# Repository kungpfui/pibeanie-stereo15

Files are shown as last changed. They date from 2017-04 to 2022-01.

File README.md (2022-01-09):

Pibeanie Stereo15
=================
a [Raspberry Pi] stereo amplifier [HAT] with 2 x 7.5 Watt HiFi output power.

The Problem
-----------
There are stereo amplifier hats on the market like the [Hifiberry Amp+] which work fine and are affordable. I own a Hifiberry Amp+ but this hat has some limitations which result in this little PCB project.

### Existing Limitations ###
- no possibility to mount the [Raspberry Pi 7" display] in an easy way together with the amplifier hat because the PCB has no cutout for the display flex-cable
- no pin header to supply the [Raspberry Pi 7" display] from the hat directly
- on-board 5 Volt DC/DC converter is limited to ~1.0 Ampere
- no infrared receiver

and last and least: as a professional PCB designer I was a little bit shocked by the PCB design of the [Hifiberry Amp+]. There are very small traces where high currents flow and the component placement of the audio output stage (HF filters) and step-down converter is ridiculous. I expect a lot of unwanted high frequency noise with that PCB design.

The Idea
--------
- a PCB which is kernel-driver-compatible to [Hifiberry Amp+]. That's easy because the audio IC is TI's [TAS5713] which is supported by the Linux kernel and there is only one possibility to connect this chip to the [Raspberry Pi].
- 5V / 3A step-down converter and the possibility to supply the [Raspberry Pi 7" display]
- infrared receiver connectable e.g. [Vishay TSOP32xxx Series]
- EEPROM for device tree BLOBs
- reverse polarity protection
- inrush current limiter

----------

The Realized Board
------------------
My Pibeanie Stereo15

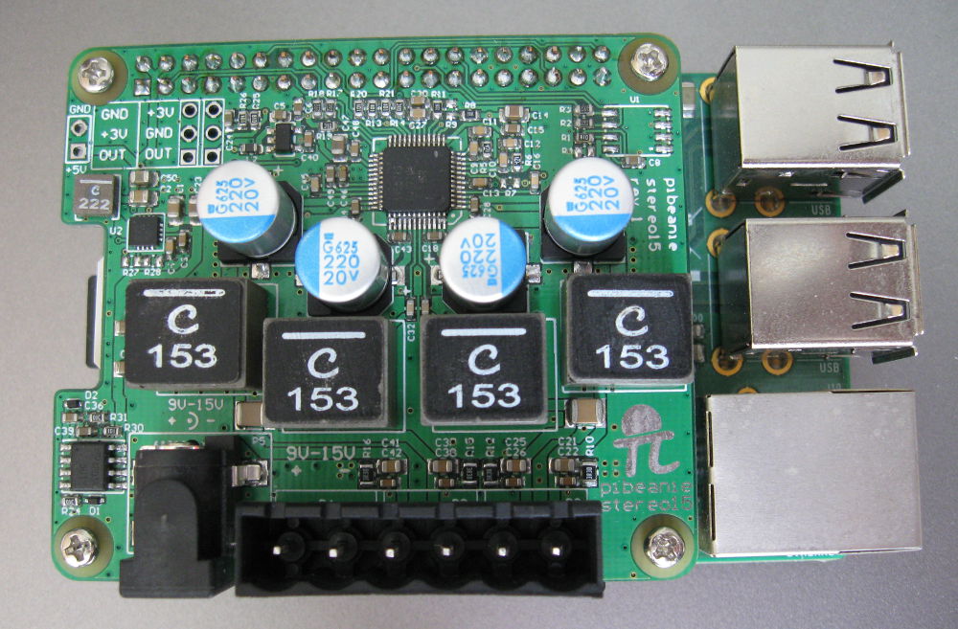
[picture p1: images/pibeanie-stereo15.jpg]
Pibeanie Stereo15


a cheap, proof of concept, 2-layer PCB which does work really proper

- [AO4803A] P-FET, with <46mOhm RDSon does the reverse polarity protection and in-rush current limiting.
- [TI TPS62133] 5V/3A step-down converter powers the Raspberry Pi and easily an additional Raspberry Pi 7" display ... and USB hard drives.
- [TAS5713] class D amplifier with a superb output filter design and superior 15000 hour @ 105°C low ESR (23mOhm!) [Nippon Chemi Con PXG Series] polymer aluminum decoupling capacitors. They should last forever!
- solder-pads for optional IR receiver. Vishay TSOP32xxx series.
- solder-pads for device tree blob EEPROM (which is not tested nowadays)
- modular connector (I like them) and 5.5/2.1mm jack. Cheap screw terminals would work as well.

### Filter Design & EMI ###
My expectations: My PCB design generates less high frequency distortion on the audio output lines than my old [Hifiberry Amp+]. Measurements with a digital scope on left and right audio lines show the following signals when driven without any audio signal.

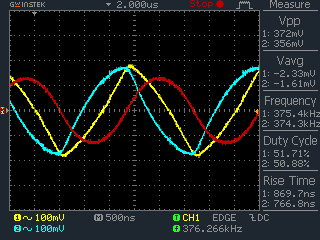
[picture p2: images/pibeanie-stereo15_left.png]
left channel
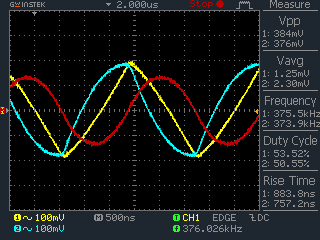
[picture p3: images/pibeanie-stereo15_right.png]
right channel
 

The base frequency of 375kHz can't be filtered out completely but it is far too high to be heard.
The red line is the calculated differential signal between + and - (or vice versa) of a single audio channel. Instead of a speaker a resistive load of 8.91 Ohm was connected.

In comparison: The signal of my Hifiberry Amp+ shows high frequency switching noise with the same measurement setup ... and + and - connections are reversed which doesn't really matter.

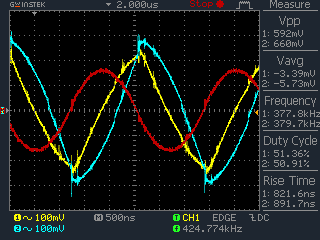
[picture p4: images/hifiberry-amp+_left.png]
left channel
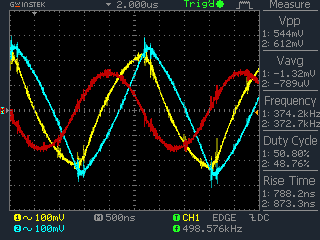
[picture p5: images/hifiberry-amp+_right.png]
right channel
 

### Downsides ###
This design is limited by the maximum input voltage of 17V which is defined by the [TI TPS62133] DC/DC converter. So the maximum audio output power is limited to around 2x10 Watt @ 8 Ohm. Personally, I supply this audio amplifier with a 12V/3A power supply and get only 7.5 Watt @ 8 ohm per channel or around 11W @ 4ohm. I can live with that audio power.

I also made some temperature measurments at 4 and 8 Ohm load and maximum sine amplitude. The maximum temperature measured after ~5 minutes at 4 ohm was 107°C. That's a little bit hot. The [TAS5713] has an over-temperature shutdown which would come to life at 150°C. I didn't want to test it with my unique board. Well, at 8 Ohm the temperature was only around 80°C.

Nowadays I would take a different DC/DC converter. [TI TPS54302] wouldn't limit the supply voltage anymore but needs a much bigger, more expensive, choke.

Component prices could make this Raspberry Pi hat a little bit questionable. I got most parts as free engineering samples. Building this hat in low quantities does you make a poor man. The most expensive parts are the coils from Coilcraft. 4 x XAL1010-153ME does cost around 25$ at Mouser and, honestly, they are heavily oversized. Take a look at the BOM for a complete overview.

I've created a 2 layers PCB instead of 4 layers because 2 layers PCBs are much cheaper especially when ordered in China. I've ordered a bunch of PCBs and a stencil at [ShenZhen2U]. The parts were placed by hand and a cheap reflow oven has done the rest.
Well, with a 2-layer PCB heat dissipation becomes an issue when running at the power limit but my design showed a lower maximum temperature than the 4-Layer Hifiberry Amp+ PCB under similar conditions. In my opinion, no wonder. My copper surfaces are exposed to the air, on the Hifiberry Amp+ PCB you have to search the copper areas.

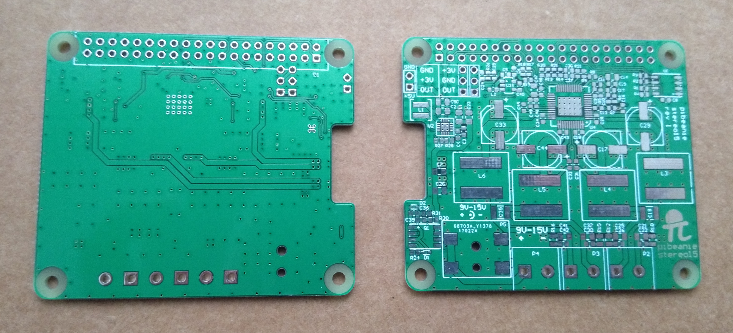
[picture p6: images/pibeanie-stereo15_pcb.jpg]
Unpopulated PCB


### Impressions ###
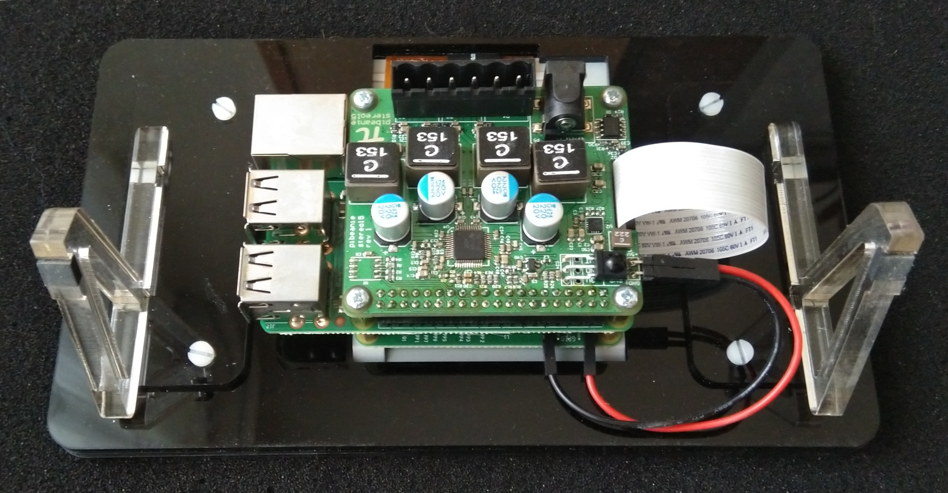
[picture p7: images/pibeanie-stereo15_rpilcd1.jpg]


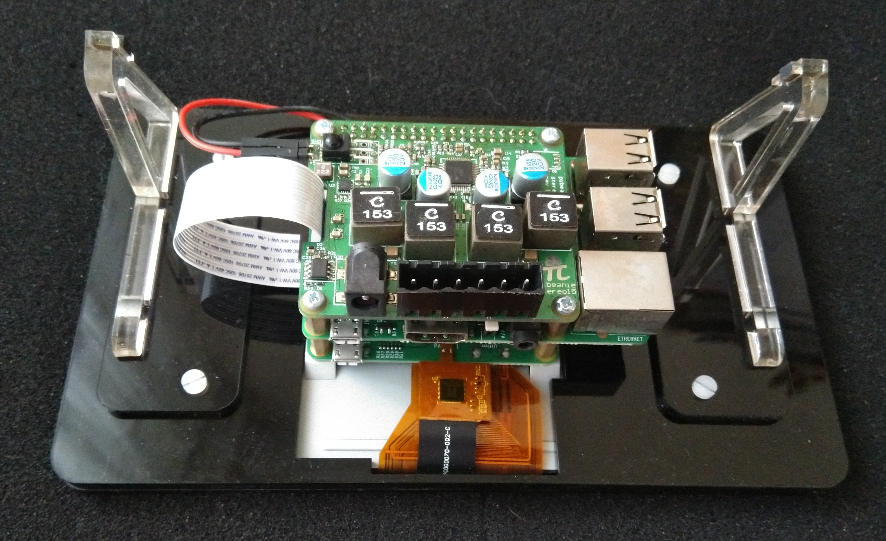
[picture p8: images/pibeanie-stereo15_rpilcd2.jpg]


[Raspberry Pi]: https://www.raspberrypi.org/
[Raspberry Pi 7" display]: https://www.raspberrypi.org/blog/the-eagerly-awaited-raspberry-pi-display/
[HAT]: https://www.raspberrypi.org/blog/introducing-raspberry-pi-hats/
[Hifiberry Amp+]: https://web.archive.org/web/20160708091429/https://www.hifiberry.com/ampplus/
[TAS5713]: https://www.ti.com/product/TAS5713/description
[TI TAS5713 datasheet]: https://www.ti.com/lit/ds/symlink/tas5713.pdf
[TI TAS5713 user guide]: https://www.ti.com/lit/pdf/slou281
[Nippon Chemi Con PXG Series]: https://www.chemi-con.co.jp/en/products/detail-condenser.php?part_number=APXG200ARA221MHA0G
[Vishay TSOP32xxx Series]: https://www.vishay.com/docs/82489/tsop322.pdf
[AO4803A]: http://www.aosmd.com/pdfs/datasheet/AO4803A.pdf
[TI TPS62133]: https://www.ti.com/product/TPS62133
[TI TPS54302]: https://www.ti.com/product/TPS54302
[ShenZhen2U]: https://www.shenzhen2u.com/

[pibeanie-stereo15.jpg]: https://github.com/kungpfui/pibeanie-stereo15/blob/master/images/pibeanie-stereo15.jpg "Pibeanie Stereo15"
[pibeanie-stereo15_pcb.jpg]: https://github.com/kungpfui/pibeanie-stereo15/blob/master/images/pibeanie-stereo15_pcb.jpg "Pibeanie Stereo15 PCB"
[pibeanie-stereo15_rpilcd1.jpg]: https://github.com/kungpfui/pibeanie-stereo15/blob/master/images/pibeanie-stereo15_rpilcd1.jpg "Pibeanie Stereo15 with Raspberry Pi 7 inch display"
[pibeanie-stereo15_rpilcd2.jpg]: https://github.com/kungpfui/pibeanie-stereo15/blob/master/images/pibeanie-stereo15_rpilcd2.jpg "Pibeanie Stereo15 with Raspberry Pi 7 inch display"
[pibeanie-stereo15_left.png]: https://github.com/kungpfui/pibeanie-stereo15/blob/master/images/pibeanie-stereo15_left.png "Zero audio signal, left channel"
[pibeanie-stereo15_right.png]: https://github.com/kungpfui/pibeanie-stereo15/blob/master/images/pibeanie-stereo15_right.png "Zero audio signal, right channel"
[hifiberry-amp+_left.png]: https://github.com/kungpfui/pibeanie-stereo15/blob/master/images/hifiberry-amp+_left.png "Zero audio signal, left channel"
[hifiberry-amp+_right.png]: https://github.com/kungpfui/pibeanie-stereo15/blob/master/images/hifiberry-amp+_right.png "Zero audio signal, right channel"

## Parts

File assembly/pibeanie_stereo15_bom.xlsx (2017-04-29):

 | Bill Of Material |  |  | Pibeanie Stereo15
 |  | Source: | pibeanie-stereo15.PrjPcb |  |  | Source: | https://github.com/kungpfui/pibeanie-stereo15
 |  | Revision: | 1.1 |  |  | Author: | Stefan Schwendeler
 |  | Variant: | TPS62133 |  |  | E-Mail: | kungpfui@gmail.com
 |  | Report Date: | 23.04.2017 | 19:57:39
 |  | Print Date: | 2017-04-29 | 11:56:36
Quantity | Designator | Comment | Rating | Material | Footprint | Manufacturer | Manufacturer Part Number | Manufacturer Required | Distributor | Distributor Part Number
6 | C1, C7, C14, C20, C23, C47 | 10u | 10%, 25V, X5R | X5R | C 0805 | Murata | GRM21BR61E106KA73L | False
2 | C2, C50 | 22u | 20%, 10V, X5R | X5R | C 0805 | Murata | GRM21BR61A226ME51L | False
10 | C3, C15, C18, C28, C30, C34, C39, C43, C46, C48 | 100n | 10%, 50V, X7R | X7R | C 0603 | Murata | GCM188R71H104KA57D | False
1 | C4 | 3n3 | 10%, 50V, X7R | X7R | C 0603 | Murata | GRM188R71H332KA01D | False
2 | C5, C6 | 2u2 | 20%, 10V, X5R | X5R | C 0603 | Murata | GRM188R61A225ME34D | False
2 | C9, C10 | 4n7 | 10%, 50V, X7R | X7R | C 0603 | Murata | GRM188R71H472KA01D | False
2 | C11, C12 | 47n | 10%, 50V, X7R | X7R | C 0603 | Murata | GRM188R71H473KA01D | False
1 | C13 | 2n2 | 10%, 50V, X7R | X7R | C 0603 | Murata | GCM188R71H222KA37D | False
4 | C16, C31, C32, C45 | 33n | 10%, 50V, X7R | X7R | C 0603 | Murata | GRM188R71H333KA | False
4 | C17, C29, C33, C44 | 220u/20V | 20%, 20V, PolyAlu, 105°C, 15kh, 20mOhm, 3.8A | Alu Polymere | C E-D8_0 H10_2 | Nichicon;Nippon Chemi-Con | PCV1D221MCL7GS;APXG200ARA221MHA0G | True
2 | C19, C35 | 680nF/100V | 10%, 100V, X7R | X7R | C 1210 | Murata | GRM32CR72A684KA01L | False
4 | C21, C25, C37, C41 | 100nF / 100V | 10%, 100V, X7R | X7R | C 0805 | Murata | GCM21BR72A104KA37K | False
5 | C22, C26, C38, C40, C42 | 10n | 10%, 50V, X7R | X7R | C 0603 | Murata | GRM188R71H103KA01D | False
3 | C24, C36, C49 | 1u0 | 10%, 25V, X7R | X7R | C 0603 | Murata | GRM188R71E105KA12D | False
1 | C27 | 4u7 | 20%, 6.3V, X5R | X5R | C 0603 | Murata | GRM188R60J475ME01D | False
2 | D1, D2 | 10V 2% | 10V, 2%, 350mW |  | SOD-523 BI | DiodesInc | BZT585B10T | False
1 | L1 | 2u2 3A |  | Ferrite | L XLF4020 | Coilcraft | XFL4020-222ME | False | Mouser | 994-XFL4020-222MEC (http://www.mouser.ch/ProductDetail/Coilcraft/XFL4020-222MEC/)
1 | L2 | Z600 0.5A | 25%, 600Ohm@100MHz, 0.35Ohm@DC | Ferrit | L 0603 0_80 | Murata | BLM18EG601SN1 | True
4 | L3, L4, L5, L6 | 15u 15A | 20%, 15uH, 15.5A, 18.6mOhm | Ferrite | L XAL1010 | Coilcraft | XAL1010-153ME | False | Mouser | 994-XAL1010-153MED (http://eu.mouser.com/ProductDetail/Coilcraft/XAL1010-153MED/)
1 | P1 | 2.54mm Female Header |  |  | BL2X20-2_54-INVERS | WE;Sullins | 61304021821;PPPC202LFBN-RC | False
3 | P2, P3, P4 | 1x2 5mm |  |  | ST 1x2 5mm WE | WE | 691 134 710 002 | False
1 | P5 | DC Power Jack 5.5mm |  |  | P DC Power Jack PJ-002AH-SMT | CUI | PJ-002AH-SMT | False
0 | P6, P8 | TSOP32xxx/34xxx, |  |  | TSOP IR | Vishay | TSOP32xxx,TSOP34xxx | True |  |  | optional
1 | Q1 | AO4803A | 30V, 4A, 2.6Vplat, 46mOhm |  | SO-8 narrow | A&O | AO4803A | True
2 | R5, R6 | 470R | 1%, 100ppm/K, 0.1W | Thick Film | R 0603 | Vishay | CRCW0603470RFK | False
5 | R8, R14, R19, R24, R31 | 10k | 1%, 100ppm/K, 0.1W | Thick Film | R 0603 | Vishay | CRCW060310K0FK | False
4 | R10, R12, R15, R16 | 3R3 | 1%, 100ppm/K, 0.5W | Thick Film | R 0805 | Vishay | CRCW08053R30FK | False
1 | R11 | 18k2 | 1%, 100ppm/K, 0.1W | Thick Film | R 0603 | Vishay | CRCW060318K2FK | False
5 | R13, R20, R21, R26, R30 | 100R | 1%, 100ppm/K, 0.1W | Thick Film | R 0603 | Vishay | CRCW0603100RFK | False
2 | R17, R18 | 3k9 | 1%, 100ppm/K, 0.1W | Thick Film | R 0603 | Vishay | CRCW06033K90FK | False
1 | R25 | 1k0 | 1%, 100ppm/K, 0.1W | Thick Film | R 0603 | Vishay | CRCW06031K00FK | False
1 | U2 | TPS62133 |  |  | DRC16 | TI | TPS62133DRCR | True
1 | U3 | TPS79333 | -0.3 - 6V |  | SOT-23-5 | TI | TPS79333DBVR | True
1 | U4 | TAS5713 |  |  | S-PQFP-G48 | TI | TAS5713PHPR | False

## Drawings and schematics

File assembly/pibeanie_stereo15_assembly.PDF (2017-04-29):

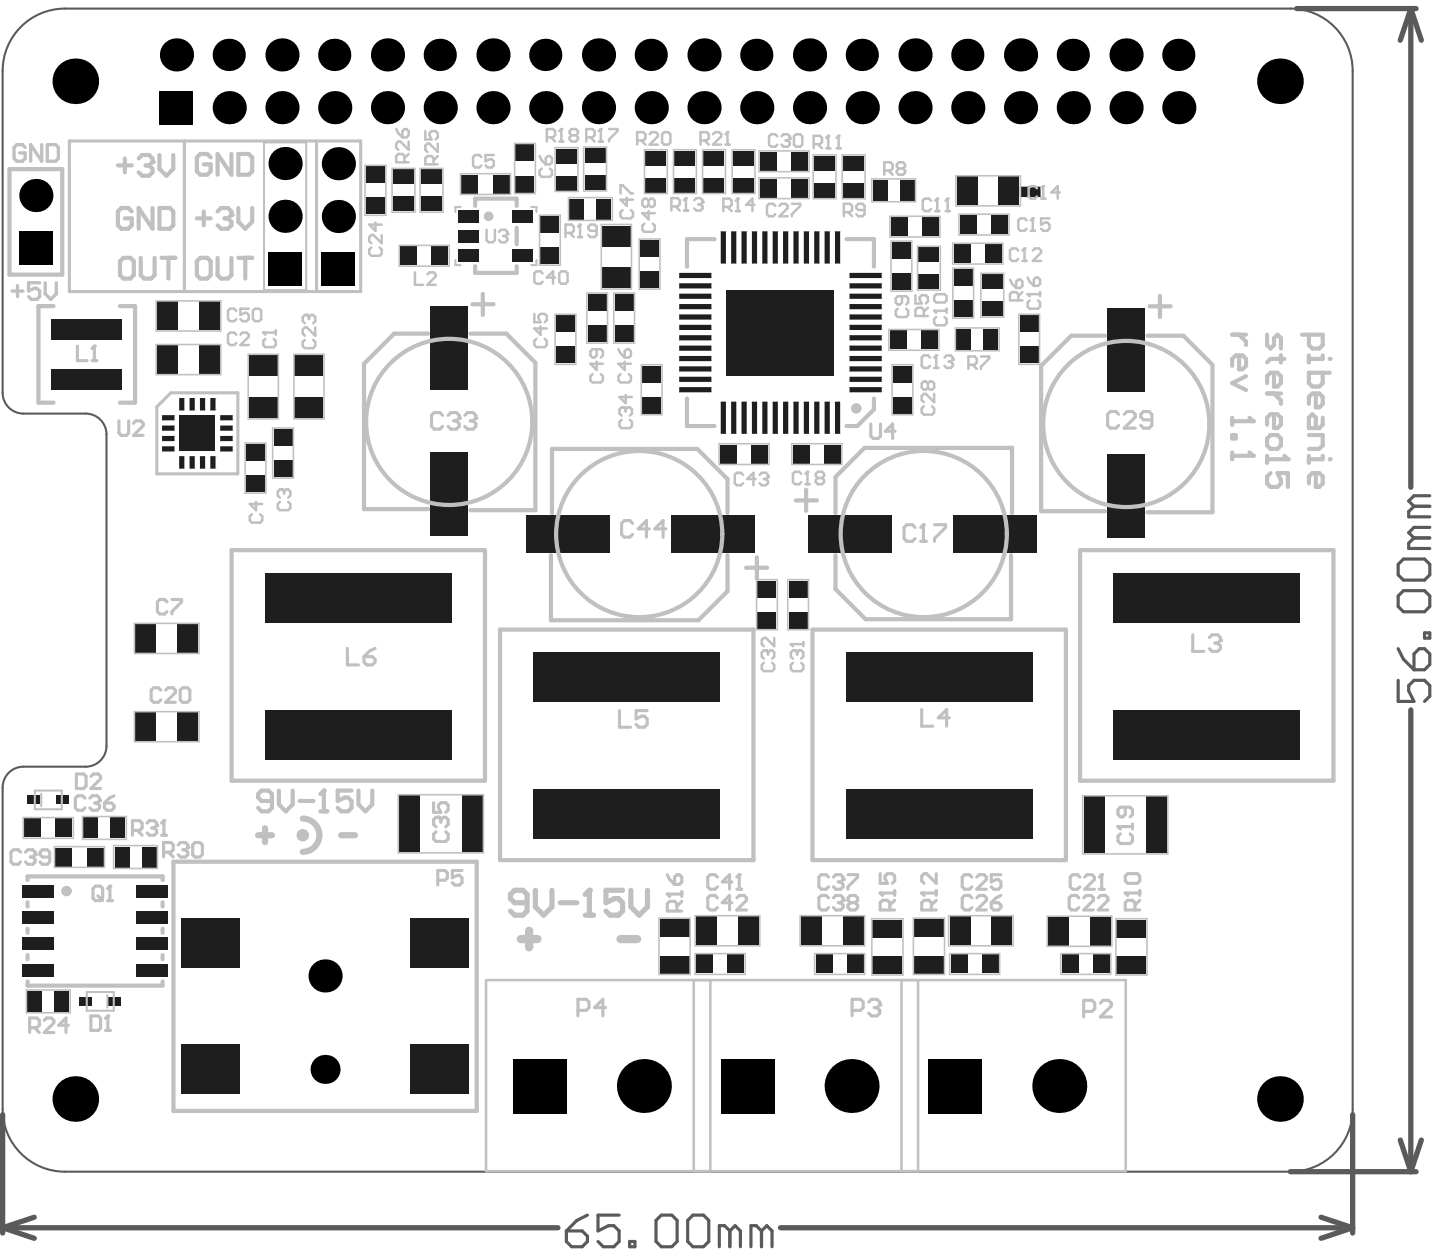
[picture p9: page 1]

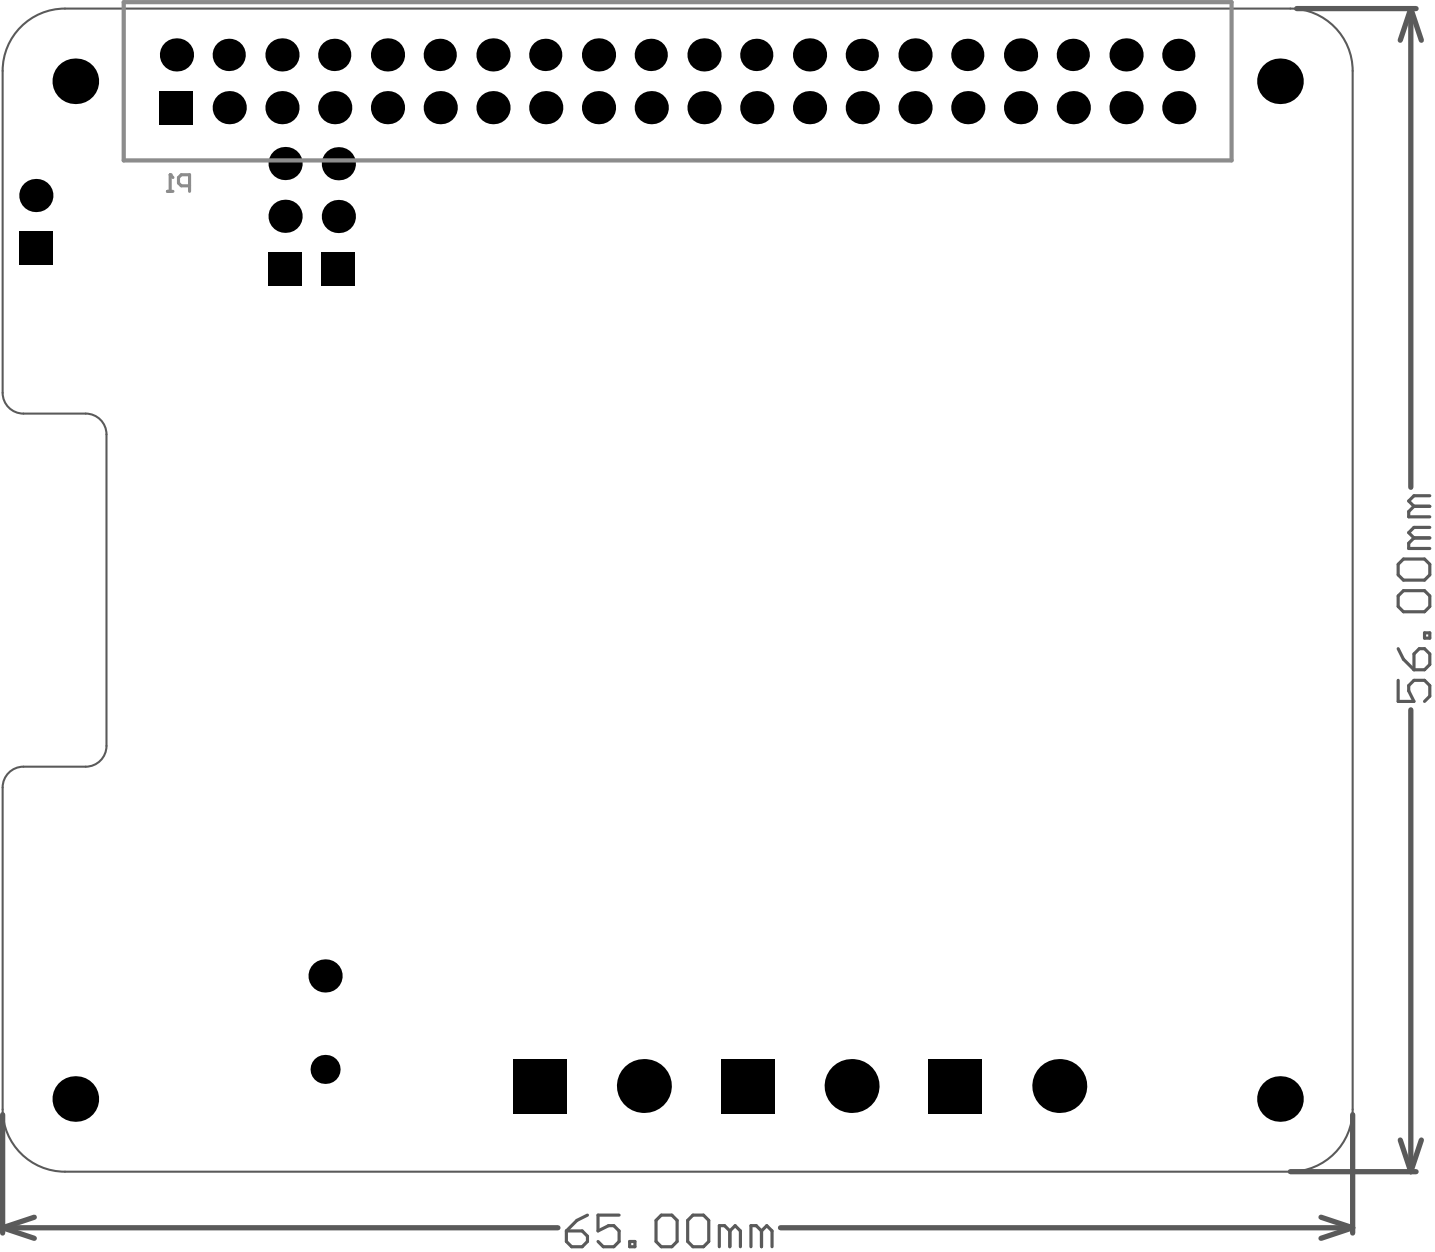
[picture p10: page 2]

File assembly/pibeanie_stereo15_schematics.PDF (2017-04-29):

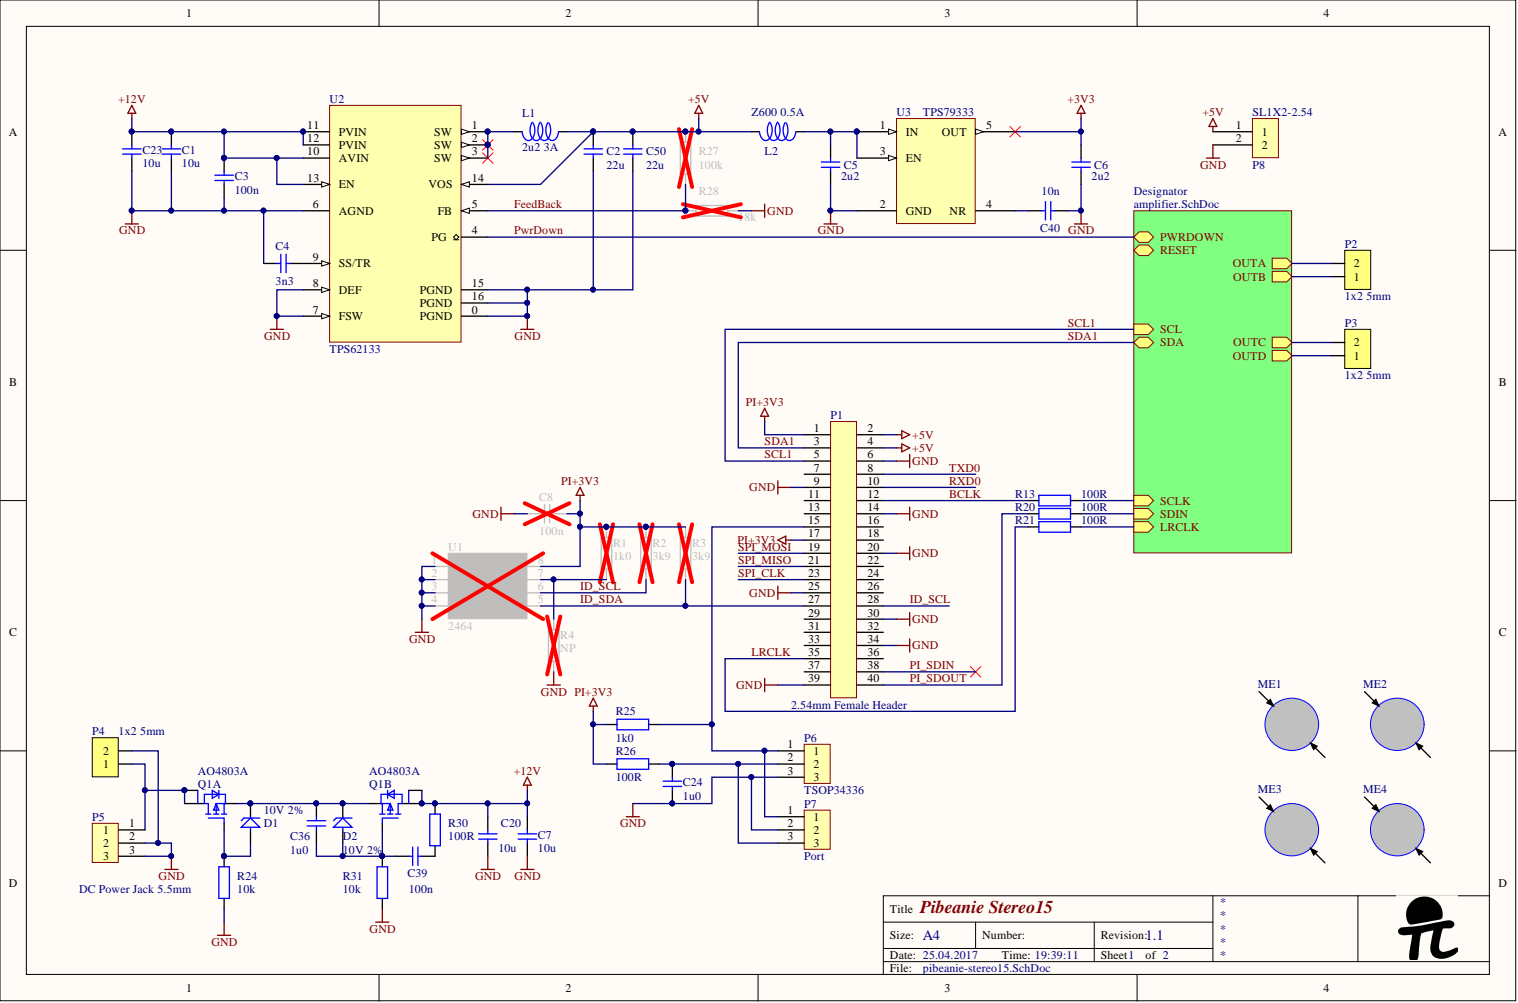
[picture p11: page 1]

C3
100n | AGND 6

2 2
3 3

Title Pibeanie Stereo15 | * * * * *

Size: A4 | Number: | Revision: 1.1
Date: 25.04.2017 Time: 19:39:11 | | Sheet 1 of 2

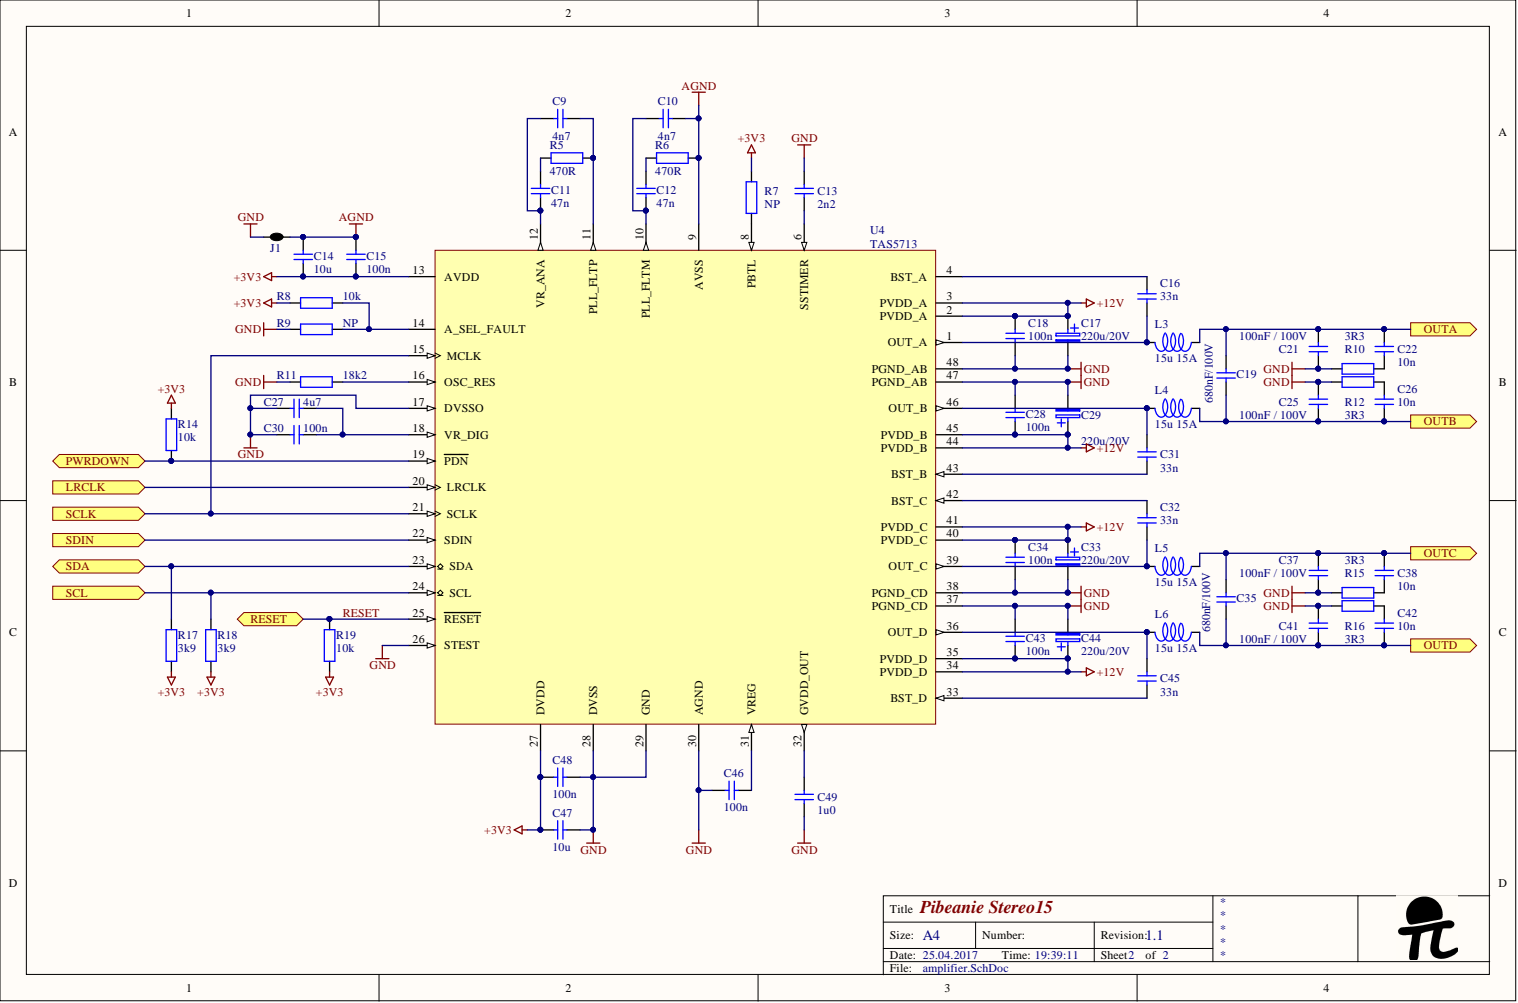
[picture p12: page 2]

T i t l e Pibeanie Stereo 1 5 | **** *

Size: A 4 | N umber: | Rev i s i o n : 1.1
Date: 2 5.0 4.2 0 1 7 T ime: 1 9 : 3 9 : 1 1 | | Sheet 2 o f 2

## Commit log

2017-04-29 initial release
    [pibeanie.GBL, pibeanie.GBO, pibeanie.GBP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]
2017-11-11 some temperature measurements at max power output
2019-09-01 unpopulated pcb photo
